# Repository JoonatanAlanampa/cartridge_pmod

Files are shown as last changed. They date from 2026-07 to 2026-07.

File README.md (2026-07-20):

# Cartridge Pmod

QSPI memory + audio Pmod for the TinyTapeout demo board and the ULX3S console
prototype. Drop-in compatible with the stock [QSPI Pmod](https://github.com/mole99/qspi-pmod)
pinout for any flash + single-PSRAM project; PMOD8 (uio[7]) carries sigma-delta
audio out instead of the second PSRAM chip select.

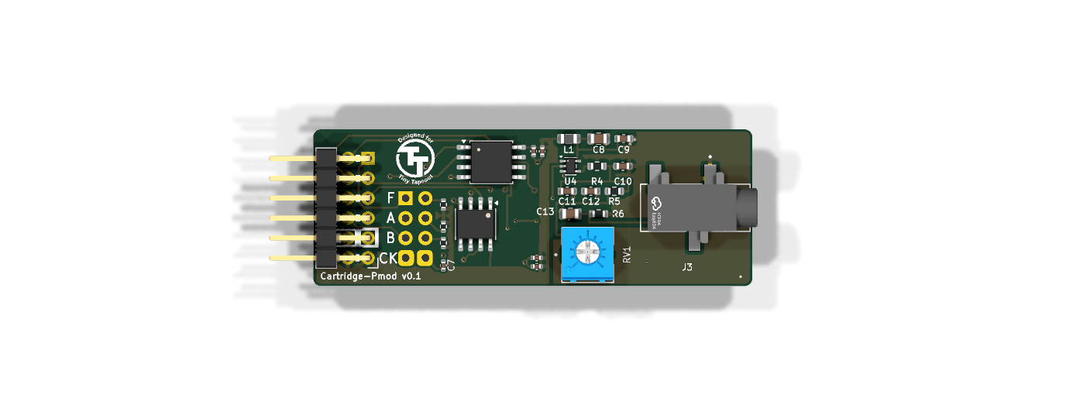
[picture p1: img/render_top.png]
Board, top


**v0.1 is at the fab**: ordered from JLCPCB 2026-07-20 (5 PCBs, 2 assembled),
tag [`fab-v0.1`](https://github.com/JoonatanAlanampa/cartridge_pmod/releases/tag/fab-v0.1). A self-checking ULX3S bring-up
bitstream is ready in [`fpga/`](fpga/README.md).

| | |
|---|---|
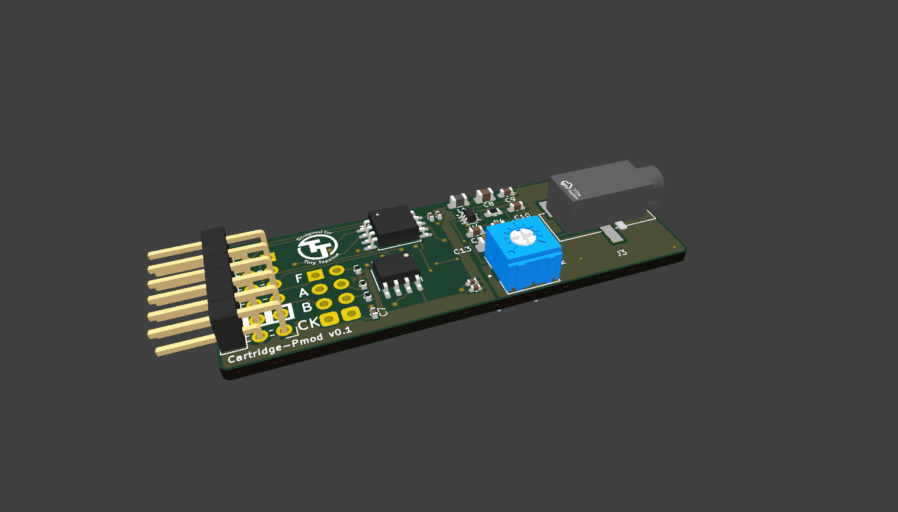
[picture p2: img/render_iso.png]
3D view
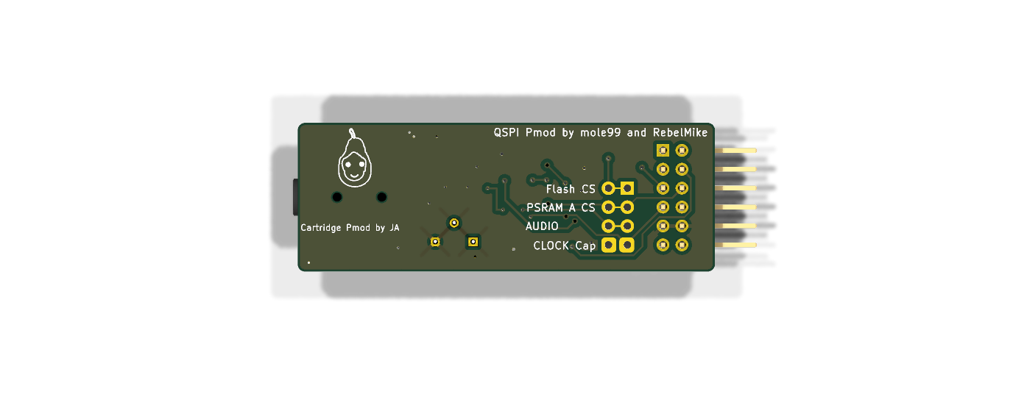
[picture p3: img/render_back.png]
Back with pearto
|  |  |
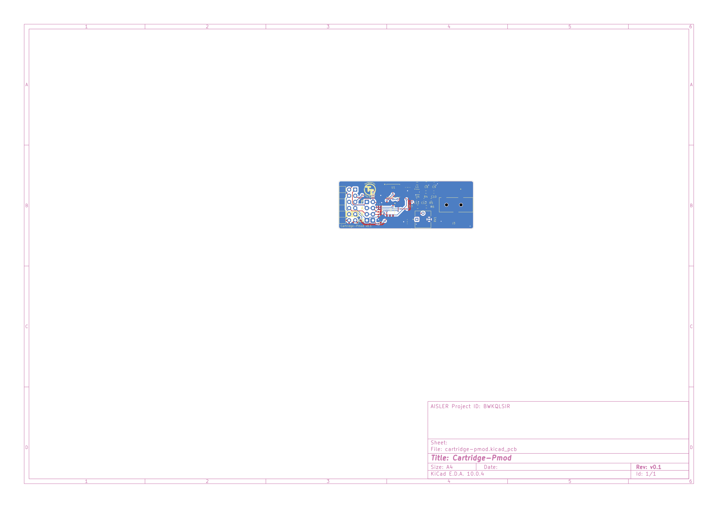
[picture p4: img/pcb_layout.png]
PCB layout
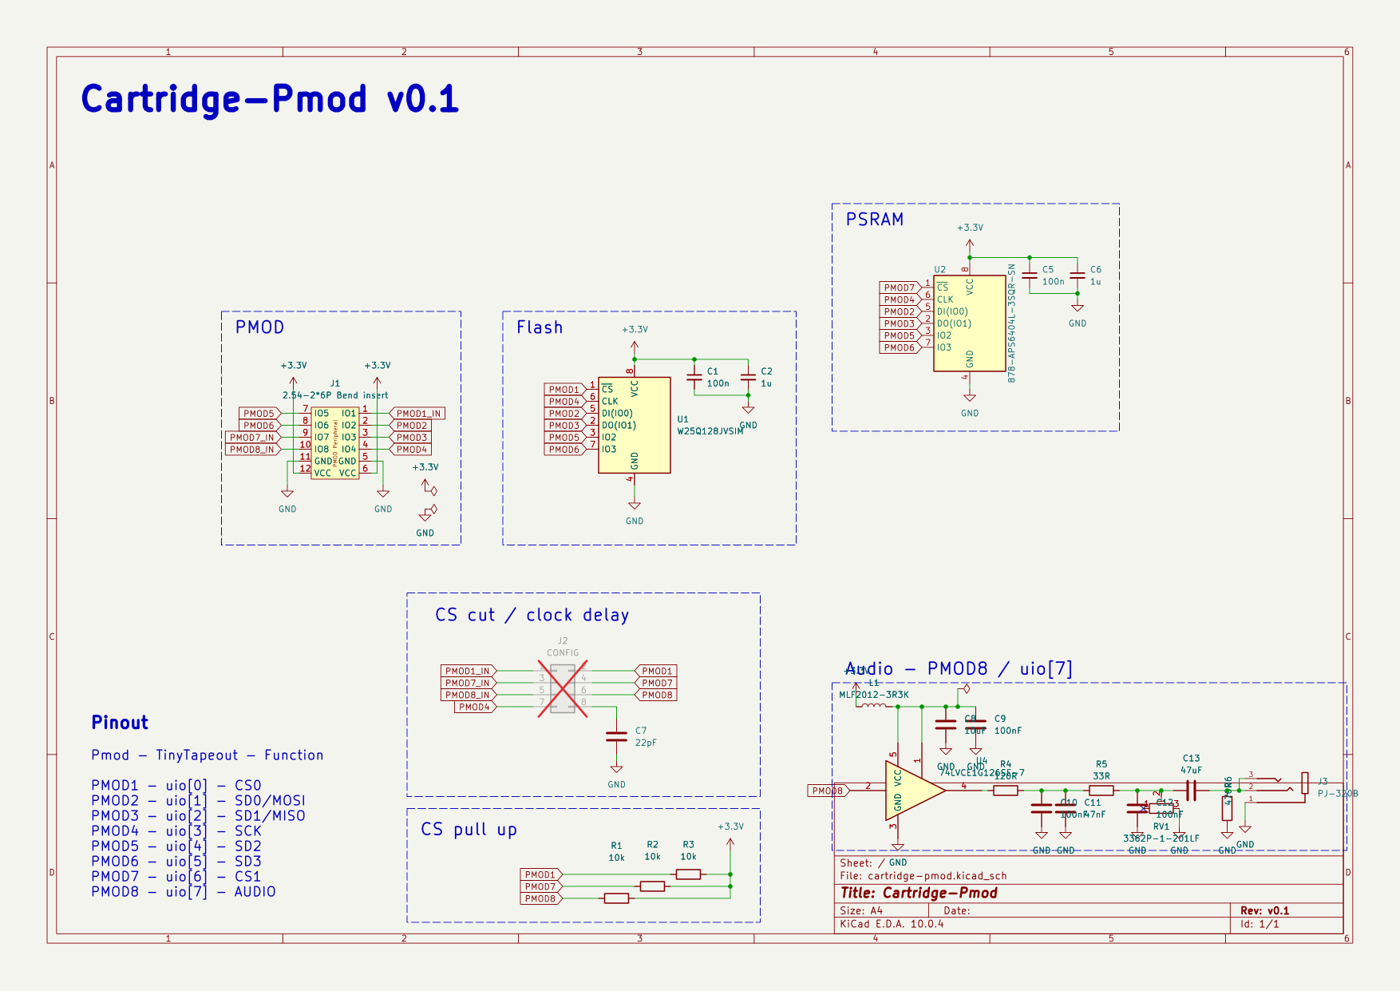
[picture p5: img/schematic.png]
Schematic
|  |  |

Full-size: [schematic PDF](cartridge-pmod.pdf) ·
[layout](img/pcb_layout.png) · [schematic PNG](img/schematic.png)

Remix of two Apache-2.0 designs:
- Memory section: [mole99/qspi-pmod](https://github.com/mole99/qspi-pmod) v2.2
  (W25Q128 16 MB flash + APS6404L 8 MB PSRAM, CONFIG jumper block, CS pull-ups)
- Audio section: [MichaelBell/tt-audio-pmod](https://github.com/MichaelBell/tt-audio-pmod)
  rev 1.0 (buffer + 2-stage RC low-pass + AC-coupled 3.5 mm jack), piezo branch dropped

## Pinout

| Pmod  | TinyTapeout | Function | Note |
|---|---|---|---|
| PMOD1 | uio[0] | CS0 (Flash)  | CONFIG jumper to isolate |
| PMOD2 | uio[1] | SD0/MOSI | |
| PMOD3 | uio[2] | SD1/MISO | |
| PMOD4 | uio[3] | SCK | CONFIG jumper pair adds 22 pF clock delay |
| PMOD5 | uio[4] | SD2 | |
| PMOD6 | uio[5] | SD3 | |
| PMOD7 | uio[6] | CS1 (PSRAM)  | CONFIG jumper to isolate |
| PMOD8 | uio[7] | AUDIO (sigma-delta / PWM in) | CONFIG jumper to isolate; ≥200 kHz carrier recommended |

## Modes

- **Console / full**: all CONFIG jumpers closed — flash + PSRAM + audio at once
  (game-console cartridge: code XIP from flash, PSRAM work RAM, audio on uio[7]).
- **Universal audio Pmod**: CS0/CS1 jumpers open — memories held in standby by
  10 k pull-ups, board is a plain audio Pmod for any project driving uio[7].
- **QSPI-compat**: audio jumper open — behaves as the stock QSPI Pmod minus
  PSRAM B (projects using only CS0/CS1 work unmodified).

## Audio chain (from tt-audio-pmod)

PMOD8 → 74LVCE1G126 buffer (ferrite-filtered 3.3 V rail, OE tied high) →
120 Ω → 100 nF‖47 nF → 33 Ω → 100 nF (2-stage RC LPF) → 200 Ω trim shunt
(volume) → 47 µF AC coupling → PJ-320B jack (tip+ring mono, 470 Ω DC
reference). Buffer input is high-impedance: audio taps the bus without
loading it.

## Status

- [x] Schematic complete, netlist machine-verified against both upstream
      designs (`tools/netlist_check.py`)
- [x] PCB layout: 56.3 × 20.1 mm, fully placed + routed (largely via pcbnew
      scripting), ERC 0 / DRC 0-unconnected, 0 silk warnings; only remaining
      DRC errors are the intentional CONFIG cut-trace feature + one upstream
      starved-thermal
- [x] Fab: **ordered at JLCPCB 2026-07-20** (tag `fab-v0.1`) — 5 PCBs,
      2 assembled (Economic, incl. the THT Pmod header), $71.76 all-in;
      see [FABRICATION.md](FABRICATION.md) for the export recipe and the
      ordering lessons (J1 rotation, PSRAM LCSC number, PCBA remark)
- [x] ULX3S bring-up harness: flash/PSRAM ID + memory test + 440 Hz test
      tone + UART report, plug orientation autodetected; simulated in both
      orientations (cocotb + icarus), 898 LUTs — see [fpga/](fpga/README.md)
- [ ] Boards arrive (~3 weeks): run the
      [first-power-up checklist](fpga/README.md#first-power-up-checklist-per-board--do-steps-1-2-before-plugging-in)

## Tools

- `tools/sch_analyze.py <file.kicad_sch>` — list all top-level elements with
  positions
- `tools/netlist_check.py [file]` — derive and print the netlist from wire
  geometry (poor man's ERC)
- `tools/build_cartridge.py` — the one-shot surgery script that generated the
  schematic from the two reference designs (kept for provenance; do not re-run)

Reference designs are vendored read-only under `refs/`.

Licensed Apache-2.0 (same as both upstream designs).

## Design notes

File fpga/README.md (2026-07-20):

# Cartridge Pmod bring-up + flash-writer on the ULX3S 85F

Self-checking harness: probes the flash + PSRAM, runs a memory test, plays a
440 Hz test tone into the audio jack, and prints a verdict on the USB serial
port. After the tests, the same bitstream turns the UART into a **flash
writer** — `flash_cartridge.py` pushes any binary image into the cartridge's
W25Q128, which is how program images get onto the cartridge for
TinyRV32-XIP boot (see `tt-riscv/fpga/`). Simulated against behavioral
W25Q128/APS6404 models: both plug orientations + a full
erase/program/verify pass (`test/`).

## Build & flash

```powershell
powershell -File fpga\synth.ps1                      # -> fpga\build\cartridge_bringup.bit
openFPGALoader -b ulx3s fpga\build\cartridge_bringup.bit
```

Simulate: `python fpga\test\run.py` (runs both plug orientations).

## First power-up checklist (per board — do steps 1-2 BEFORE plugging in!)

1. **Bare-board short check** (multimeter, cartridge alone on the bench):
   continuity between the Pmod plug's VCC (pins 6/12, the column nearest the
   board) and GND (pins 5/11) must be OPEN (a capacitor charge blip is fine,
   a hard beep is not).
2. **Plug position**: cartridge goes into the **J1 header, pins 1-12** — the
   6 columns at the END of the left female header. ULX3S silk numbers the
   pins; the cartridge's VCC/GND columns must land on pins 1/2 (3.3V) and
   3/4 (GND). Verify once with the meter: cartridge VCC pin to ULX3S 3.3V
   should beep. Which cartridge ROW lands on GP vs GN does not matter — the
   bitstream autodetects it (LED4 tells you which).
3. Flash the bitstream, open a serial terminal at **115200 8N1** on the
   ULX3S FTDI port. Report format:

   ```
   CARTRIDGE-PMOD BRINGUP
   MAP A                    <- or B; ! = flash never answered (both rows tried)
   FLASH EF4018 PASS        <- W25Q128 JEDEC ID
   PSRAM 0D5D PASS          <- APS6404 MF+KGD
   MEM PASS                 <- 2 write/read patterns + aliasing re-read
   FLASH@0 FFFFFFFF         <- first 4 flash bytes (blank chip = FF)
   DONE
   ```

4. **LEDs**: 0 heartbeat, 1 flash OK, 2 PSRAM OK, 3 mem OK, 4 mapping B,
   5 done, 6 any-fail, 7 audio on. **BTN1 re-runs** the whole sequence.
5. **Audio**: after all tests pass, a 440 Hz sine plays on the cartridge
   jack (sigma-delta through the RC + buffer chain). Headphones in, set
   level with RV1 (small screwdriver). Verifies the whole analog path.
6. If `MAP !` / all-fail: check the CONFIG jumpers on the cartridge back
   (F and A rows must be in their default state), re-seat the Pmod, check
   3.3V on the cartridge VCC pin while powered.

## Flashing a program image

After the bring-up report (any time the LEDs show DONE), the UART accepts
binary flash-writer commands. From the PC:

```powershell
pip install pyserial          # once
python fpga\flash_cartridge.py COM7 hello.bin          # erase+write+verify
python fpga\flash_cartridge.py COM7 img.bin --base 0x10000
```

(Find the COM port in Device Manager — the ULX3S FTDI channel; on Linux
`/dev/ttyUSB0`.) The script waits out the report, handshakes on the JEDEC
ID, erases the covered 4 KB sectors, programs 256-byte pages, and reads
everything back. Protocol (MSB-first fields, handled in `bringup_top.sv`
with WREN + SR1 busy-polling internal):

| cmd | bytes | reply |
|-----|---|---|
| `I` | — | 3 ID bytes (`EF 40 18`) |
| `E` | addr24 | `K` after sector erase completes |
| `P` | addr24 + 256 data | `K` after page program completes |
| `R` | addr24 | 256 bytes read from addr |

Then flash `tt-riscv`'s `rv32_cartridge.bit` — TinyRV32 boots the image
in place. Day-one sequence: bring-up PASS -> flash hello.bin -> swap
bitstream -> "Hello" on the same serial port.

## What this proves / what's next

PASS here = the cartridge hardware is fully validated for the console
project: QSPI bus wiring, both memories, the audio chain, and the TT-pinout
compatibility (pins 1-7 identical to the stock QSPI Pmod).

Next steps on this same setup:
- quad-mode + clock sweep (the bring-up runs 12.5 MHz single-bit SPI)
- race-the-beam console prototype (video via ULX3S GPDI while waiting for
  the Tiny VGA Pmod)

## Notes

- The APS6404 tCEM (8 us max CS-low) is respected by keeping bursts to
  4 bytes; the testbench model enforces it with a fatal assertion.
- SD2/SD3 (flash /WP, /HOLD) are actively driven high during SPI — they
  have no pull-ups on the cartridge.
- The ULX3S J1 power pins feed from the "2V5_3V3" net — stock boards ship
  it at 3.3 V; if yours was modified for 2.5 V I/O, put it back before
  plugging the cartridge.

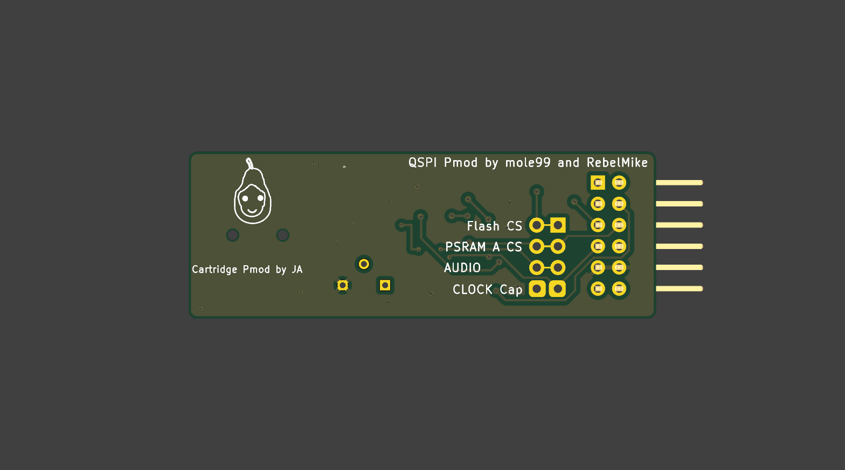
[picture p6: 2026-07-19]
render_bottom.png

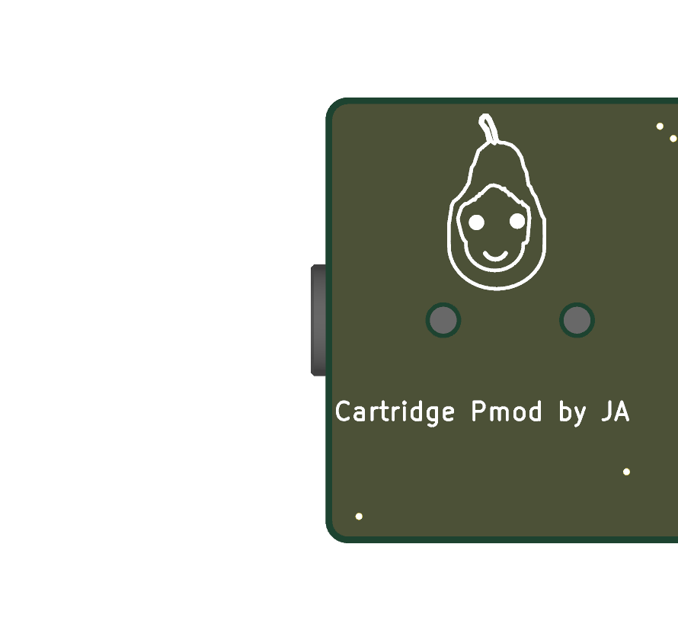
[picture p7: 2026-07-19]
rb_crop.png

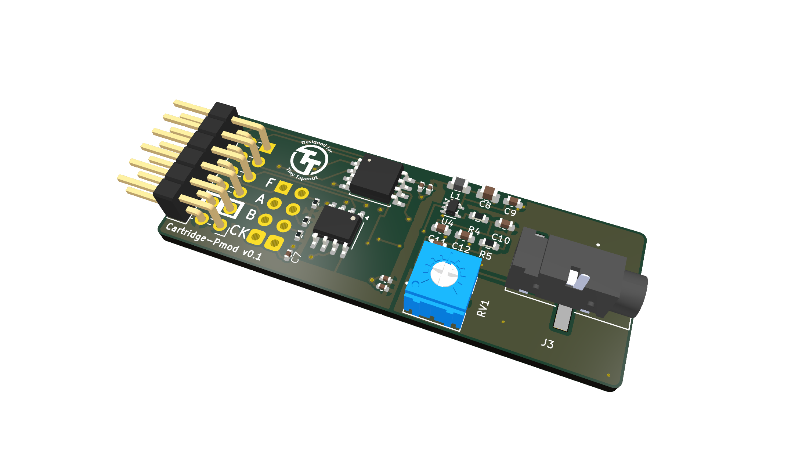
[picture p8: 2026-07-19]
render_3d.png

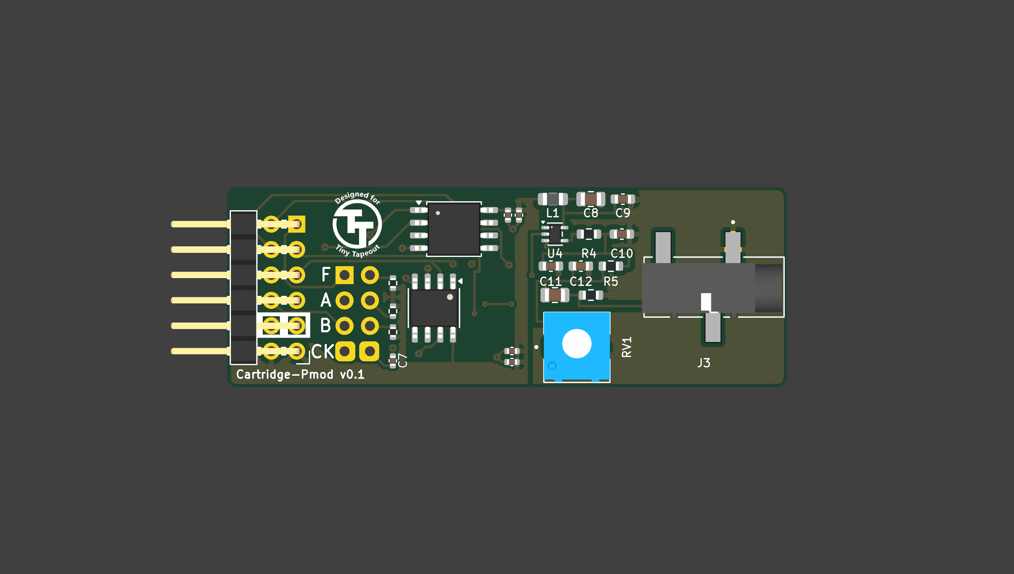
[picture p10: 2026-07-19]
render_zoom.png

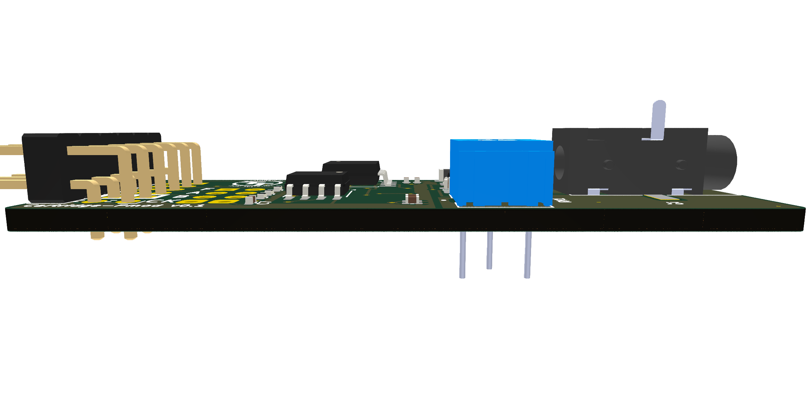
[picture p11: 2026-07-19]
render_side.png

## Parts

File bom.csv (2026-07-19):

Reference | Value | Footprint | QUANTITY | LCSC Part | MPN
C1,C5 | 100n | Capacitor_SMD:C_0402_1005Metric | 2 |  | 0402YC104KAT2A
C2,C6 | 1u | Capacitor_SMD:C_0402_1005Metric | 2 |  | C0402C105M9PAC
C7 | 22pF | Capacitor_SMD:C_0402_1005Metric | 1 |  | 0402CG220J500NT
C8 | 10uF | Capacitor_SMD:C_0805_2012Metric | 1 | C15850
C9,C10,C12 | 100nF | Capacitor_SMD:C_0603_1608Metric | 3 | C14663
C11 | 47nF | Capacitor_SMD:C_0603_1608Metric | 1 | C1622
C13 | 47uF | Capacitor_SMD:C_0805_2012Metric | 1 | C16780
J1 | 2.54-2*6P Bend insert | tt:PinHeader_2x06_P2.54mm_PMODPeriph2B | 1 | C60565 | 2.54-2*6P
J2 | CONFIG | Connector_PinHeader_2.54mm:PinHeader_2x04_P2.54mm_Vertical | 1
J3 | PJ-320B | LCSC:BOOMELE_PJ-320B | 1 | C2884998
L1 | MLF2012-3R3K | Inductor_SMD:L_0805_2012Metric | 1 | C2941578
R1-R3 | 10k | Resistor_SMD:R_0402_1005Metric | 3 |  | 0402WGF1002TCE
R4 | 120R | Resistor_SMD:R_0603_1608Metric | 1 | C22787
R5 | 33R | Resistor_SMD:R_0603_1608Metric | 1 | C23140
R6 | 470R | Resistor_SMD:R_0603_1608Metric | 1 | C23179
RV1 | 3362P-1-201LF | LCSC:TRIM_3362P-1-102 | 1 | C124581
U1 | W25Q128JVSIM | Package_SO:SOIC-8_5.23x5.23mm_P1.27mm | 1 |  | W25Q128JVSIM
U2 | 878-APS6404L-3SQR-SN | Package_SO:SOP-8_3.9x4.9mm_P1.27mm | 1 |  | APS6404L-3SQR-SN
U4 | 74LVCE1G126SE-7 | Package_TO_SOT_SMD:SOT-353_SC-70-5 | 1 | C842506

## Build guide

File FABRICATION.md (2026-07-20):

# Fabrication export guide (JLCPCB, PCB + SMT assembly)

## ORDERED 2026-07-20 (v0.1, commit 8dd7671, tag fab-v0.1)

5 PCBs + 2 assembled (Economic, top side), $71.76 all-in via Global Standard
Direct Line (13-16 business days). Breakdown: $52.34 merchandise, $16.26
shipping (incl $6.93 prepaid customs-duty deposit), $18.42->$13.16 VAT via
IOSS, -$10 coupon. NOTE: since 2026-07-01 the EU charges customs duty below
EUR 150 too — Direct Line prepays it; courier (non-DDP) options risk a
disbursement fee at the door; DHL DDP was quoted +$24.50 over Direct Line.

Lessons from the actual order (v0.1):
- J1 rendered 90 deg rotated in the JLC placement preview (custom TT
  footprint, not in their rotation DB) — fixed with the preview's rotate
  button: pins must extend off the LEFT board edge. Re-check every order.
- Pin-1 ground truth for the preview check (board title bottom-left):
  U1 dot TOP-LEFT, U2 dot TOP-RIGHT, U4 3-pin side LEFT + dot TOP-LEFT.
- U2 PSRAM has no LCSC number in our BOM (upstream sourced via Mouser):
  match manually to APS6404L-3SQR-SN = LCSC C5333729 (~$2.94).
- C1/C5, C2/C6, R1-R3 raise "comment mismatch" warnings (our BOM carries
  MPNs, not LCSC codes) — matched parts C1525 / C52923 / C25744 verified
  correct, just tick to confirm.
- PCBA remark used (J2 is NOT in the uploaded BOM/CPL, describe visually):
  "J1 (the only THT part in the BOM, right-angle pin header): body sits on
  the board, pins intentionally extend past the LEFT board edge, orientation
  as set in the placement preview. J3 (audio jack): barrel intentionally
  overhangs the RIGHT board edge. The unpopulated 2x4 through-hole pad grid
  next to the 'F A B CK' silk labels is a solder-jumper feature -
  intentionally empty, do not populate. No other special requirements."

Target: 5 boards, assembled front side. Everything below
was verified against this project with KiCad 10.0.4 on Windows.

## Pre-flight (already done for v0.1, re-check after any edit)

1. ERC on the schematic: 0 errors
   (`kicad-cli sch erc --severity-error cartridge-pmod.kicad_sch`).
2. DRC on the board: 0 unconnected; only the 23 known-ignorable errors
   (22 CONFIG-jumper cut-trace + 1 upstream starved-thermal on R1)
   (`kicad-cli pcb drc cartridge-pmod.kicad_pcb`).
3. Zones refilled (open PCB in GUI, press **B**, save — or any tools/ script
   that ends with `ZONE_FILLER`).
4. Supplier fields present **on the board**, not only the schematic: the
   Fabrication Toolkit reads footprint fields, so `LCSC Part` must be pushed
   across with Tools → Update PCB from Schematic (F8, "update fields" ticked).
   Without it the audio-section LCSC numbers export blank. Fixed 2026-07-20.
5. J1 (Pmod header) is **JLC-assembled** (DNP cleared 2026-07-20, LCSC
   C60565, THT economic assembly). J2 (CONFIG solder jumpers) stays DNP —
   export with the exclude-DNP option so it drops out of BOM + placement.
6. Silkscreen is DRC-clean (0 silk warnings since 2026-07-20: J1's off-edge
   pin drawings deleted, all audio-section labels placed, C13/R6 shown).
7. Board committed + pushed.

## Option A — Fabrication Toolkit plugin (recommended, one click)

1. Open KiCad → **Plugin and Content Manager** → install **Fabrication
   Toolkit** (by bennymeg; made specifically for JLCPCB).
2. Open the PCB editor, click the Fabrication Toolkit icon in the toolbar.
3. It writes a `production/` folder containing:
   - `gerbers.zip` (all copper/mask/silk/edge layers + drill files)
   - `bom.csv` (grouped by value+footprint, with the **LCSC Part** field)
   - `positions.csv` (component placement / CPL, JLC-rotation-corrected)
4. Upload to jlcpcb.com — see "Ordering" below.

Headless equivalent (no GUI; same output, verified 2026-07-20):

```powershell
& "$env:LOCALAPPDATA\Programs\KiCad\10.0\bin\python.exe" -c @'
import sys, runpy
sys.path.insert(0, r"C:\Users\Joonatan Alanampa\Documents\KiCad\10.0\3rdparty\plugins")
sys.argv = ["cli", "-p", r"cartridge-pmod.kicad_pcb", "-t", "-f", "-e", "-nI"]
runpy.run_module("com_github_bennymeg_JLC-Plugin-for-KiCad.cli", run_name="__main__")
'@
```

(`-t` rotation fixes, `-f` zone refill, `-e` exclude DNP → keeps J2 out,
`-nI` non-interactive. `runpy` because the plugin dir name has hyphens.)

## Option B — pure kicad-cli (no GUI, scriptable)

Run from the project directory
(`$cli = "$env:LOCALAPPDATA\Programs\KiCad\10.0\bin\kicad-cli.exe"`):

```powershell
# gerbers (copper, mask, silk both sides, board edge)
& $cli pcb export gerbers --output fab/ `
    --layers F.Cu,B.Cu,F.Mask,B.Mask,F.Silkscreen,B.Silkscreen,Edge.Cuts `
    cartridge-pmod.kicad_pcb
# drill files (Excellon, PTH+NPTH merged is fine for JLC)
& $cli pcb export drill --output fab/ --format excellon `
    --excellon-units mm cartridge-pmod.kicad_pcb
# placement file, front side, CSV in mm
& $cli pcb export pos --output fab/positions.csv --format csv --units mm `
    --side front cartridge-pmod.kicad_pcb
# BOM with LCSC numbers
& $cli sch export bom --output fab/bom.csv `
    --fields "Reference,Value,Footprint,${'$'}{QUANTITY},LCSC Part,MPN" `
    cartridge-pmod.kicad_sch
# zip the gerbers + drill for upload
Compress-Archive fab/*.gbr, fab/*.drl fab/gerbers.zip
```

Caveat vs Option A: JLC wants specific CPL column names
(Designator, Mid X, Mid Y, Layer, Rotation) and some footprints need
rotation offsets — the Fabrication Toolkit handles both automatically,
kicad-cli output may need manual column renaming and rotation fixes in the
JLC preview. Prefer Option A for ordering; use Option B for CI/checks.

## Ordering at jlcpcb.com

1. **Add gerber file** → upload `gerbers.zip`. Check the rendered preview
   (board outline 56.3 x 20.1 mm, both silk sides, pearto visible on back).
2. PCB options: 2 layers, 1.6 mm, HASL(lead-free ok), any color, qty 5.
   Leave everything else default. "Remove Order Number" → "Specify a
   location" is NOT set up on this board — accept the printed order number
   or pay the small fee to remove it.
3. Enable **PCB Assembly**: Economic, top side, qty 2 or 5.
4. Upload `bom.csv` and `positions.csv`.
5. Parts matching page — check each line:
   - Audio section parts all carry explicit LCSC numbers
     (U4 C842506, L1 C2941578, C8 C15850, C9/C10/C12 C14663, C11 C1622,
     R4 C22787, R5 C23140, R6 C23179, RV1 C124581, J3 C2884998, J1 C60565).
   - Memory section (U1 W25Q128JVSIM, U2 APS6404L-3SQR-SN, 0402 R/C) has
     MPNs but no LCSC field — JLC usually auto-matches by MPN; verify the
     match, or search the LCSC number manually and paste it in.
   - **Do-not-place**: J2 CONFIG header is a solder-jumper pattern +
     optional pin header — confirm whether a physical header is wanted;
     if not, mark J2 DNP (the jumper pads still work with solder blobs).
6. Placement preview: verify U1/U2/U4 pin-1 orientation and RV1/J3 outline
   vs pads (these are the rotation-risk parts). Fix rotations in the JLC
   editor if a part renders rotated.
7. THT parts: J1 (Pmod header, C60565) is in the BOM/CPL for JLC economic
   THT assembly — verify in the parts-matching page that JLC accepts it for
   economic assembly; if it's flagged unsupported, either switch the order
   to Standard assembly or mark J1 "Do not place" in the JLC editor and
   hand-solder it (Pinecil fallback). J3's TH legs are anchors only, SMT
   soldered.
8. Order. Economic assembly typically adds ~1 week.

## After ordering

- Tag the repo: `git tag fab-v0.1 && git push --tags`.
- First power-up checklist: continuity 3V3-GND (multimeter, before first
  plug-in!), then flash/PSRAM ID read via TT demo board or ULX3S harness,
  then audio: drive uio7 with a sigma-delta/PWM tone >= 200 kHz carrier.

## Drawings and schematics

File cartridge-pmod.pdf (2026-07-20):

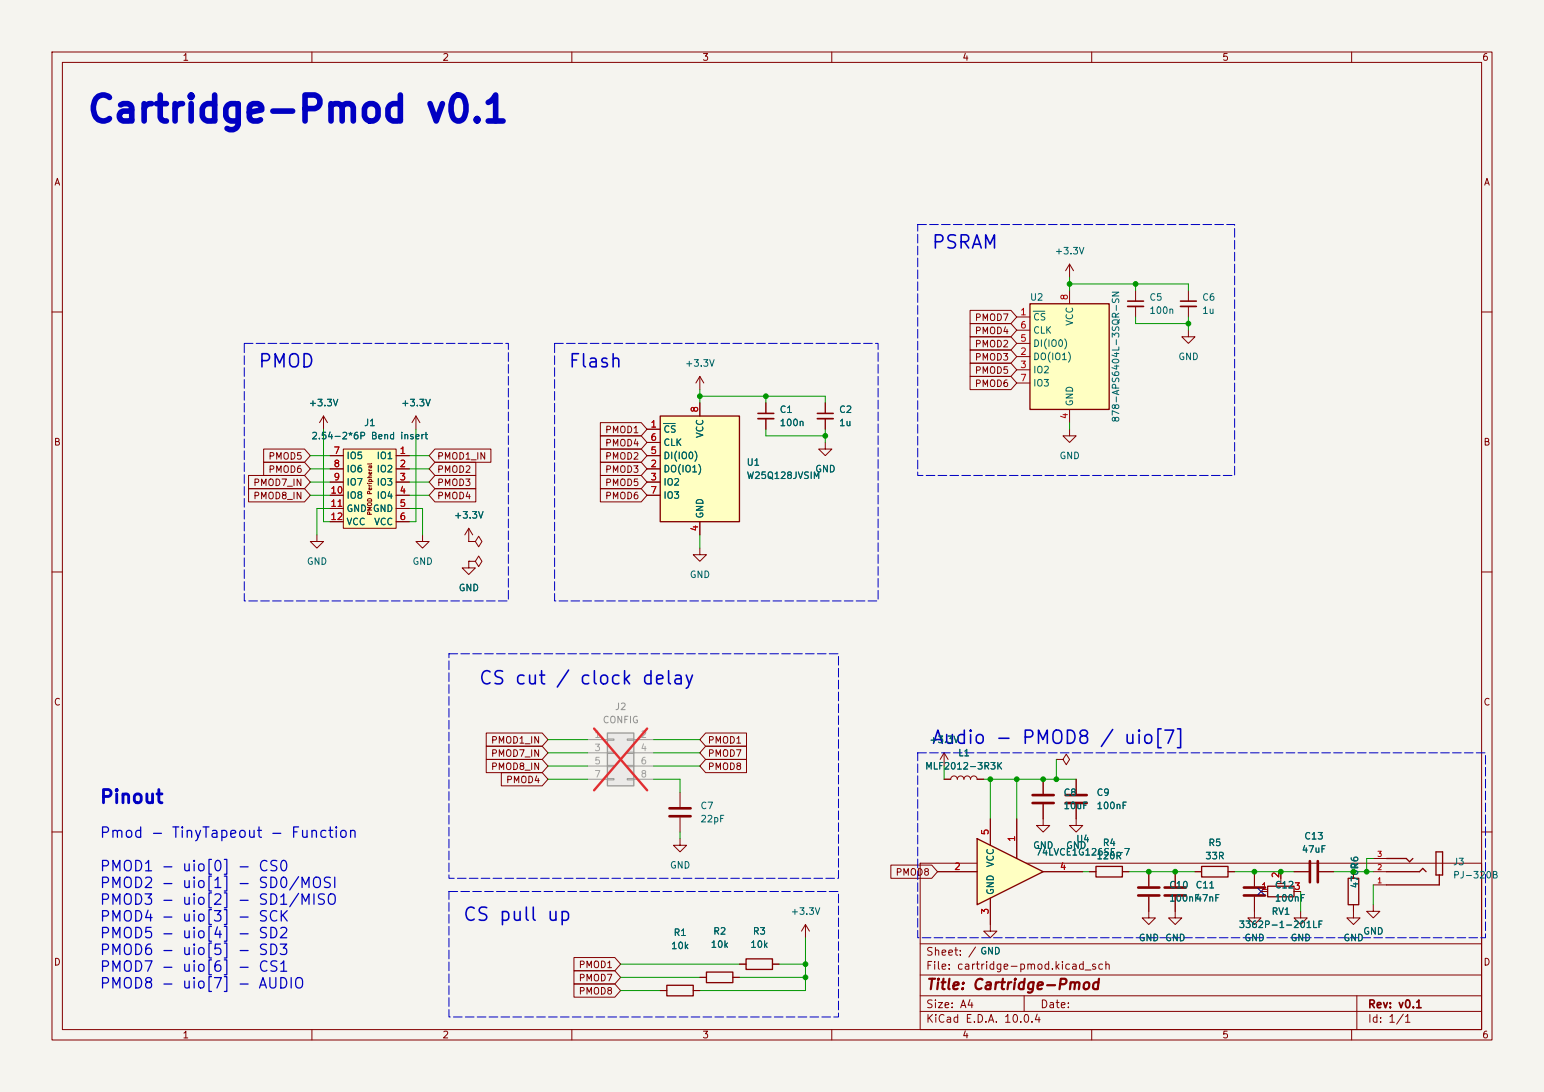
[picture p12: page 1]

CS cut / clock delay

Size: A4 | Rev: v0.1
KiCad E.D.A. 10.0.4 | Id: 1/1

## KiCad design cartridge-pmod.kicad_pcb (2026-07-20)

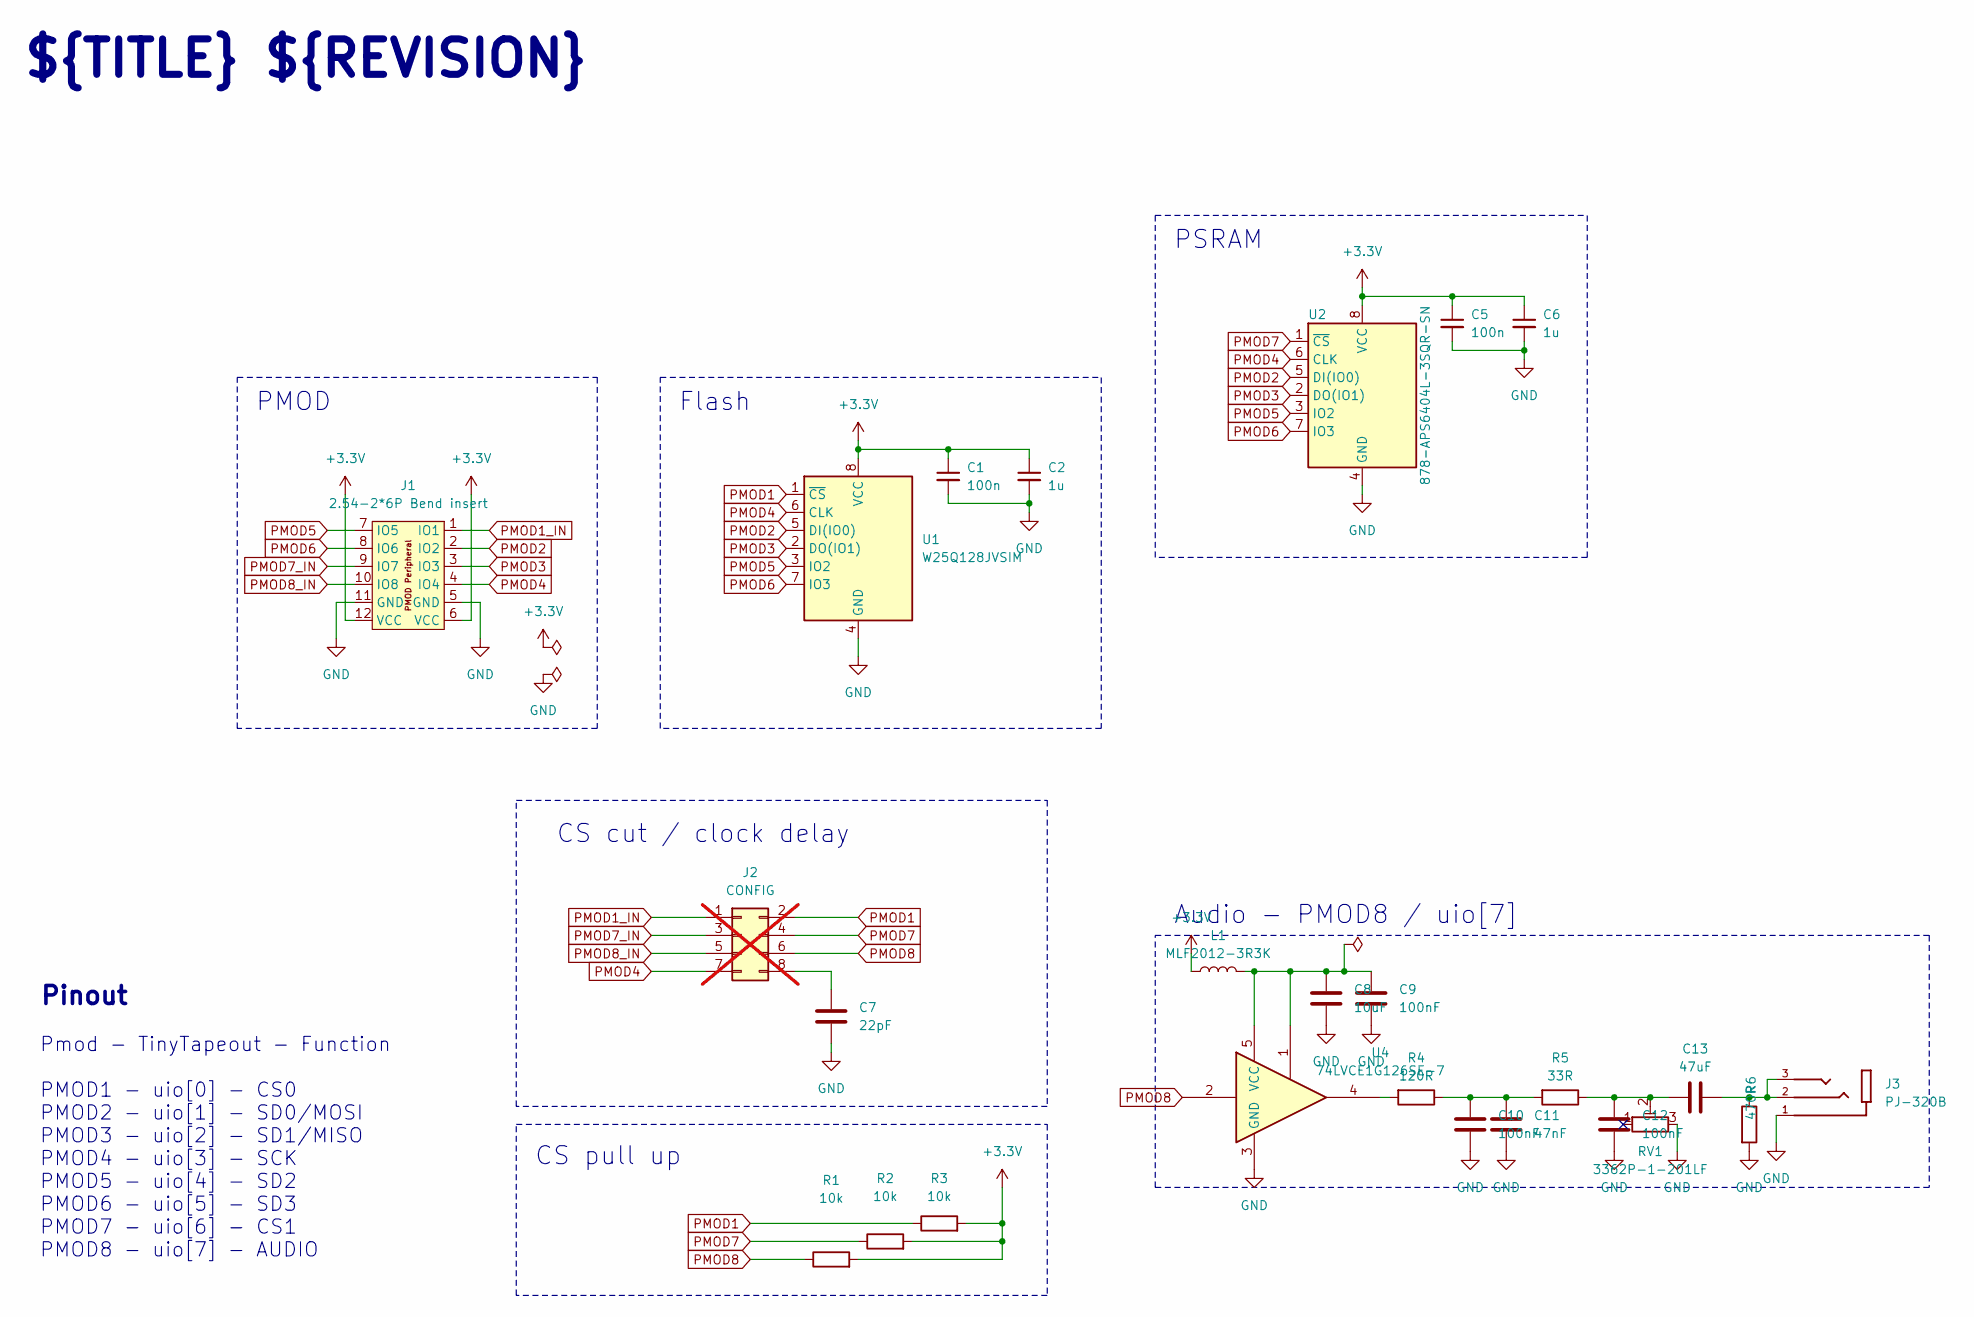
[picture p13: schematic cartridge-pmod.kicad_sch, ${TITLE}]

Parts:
C1, C5: 100n; C_0402_1005Metric; MPN 0402YC104KAT2A
C2, C6: 1u; C_0402_1005Metric; MPN C0402C105M9PAC
C7: 22pF; C_0402_1005Metric; MPN 0402CG220J500NT
C8: 10uF; C_0805_2012Metric; LCSC Part C15850
C9, C10, C12: 100nF; C_0603_1608Metric; LCSC Part C14663
C11: 47nF; C_0603_1608Metric; LCSC Part C1622
C13: 47uF; C_0805_2012Metric; LCSC Part C16780
J1: 2.54-2*6P Bend insert; PinHeader_2x06_P2.54mm_PMODPeriph2B; MPN 2.54-2*6P; LCSC Part C60565
J2: CONFIG; PinHeader_2x04_P2.54mm_Vertical; not fitted
J3: PJ-320B; BOOMELE_PJ-320B; LCSC Part C2884998
L1: MLF2012-3R3K; L_0805_2012Metric; LCSC Part C2941578
R1, R2, R3: 10k; R_0402_1005Metric; MPN 0402WGF1002TCE
R4: 120R; R_0603_1608Metric; LCSC Part C22787
R5: 33R; R_0603_1608Metric; LCSC Part C23140
R6: 470R; R_0603_1608Metric; LCSC Part C23179
RV1: 3362P-1-201LF; TRIM_3362P-1-102; LCSC Part C124581
U1: W25Q128JVSIM; SOIC-8_5.23x5.23mm_P1.27mm; MPN W25Q128JVSIM
U2: 878-APS6404L-3SQR-SN; SOP-8_3.9x4.9mm_P1.27mm; MPN APS6404L-3SQR-SN
U4: 74LVCE1G126SE-7; SOT-353_SC-70-5; LCSC Part C842506

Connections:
+3.3V: C1.1, C2.1, C5.1, C6.1, J1.6 (VCC), J1.12 (VCC), L1.1, R1.2, R2.2, R3.2, U1.8 (VCC), U2.8 (VCC)
AUDIO_BUF: R4.2, U4.4
AUDIO_N1: C10.1, C11.1, R4.1, R5.2
AUDIO_N2: C12.1, C13.2, R5.1, RV1.2
AUDIO_OUT: C13.1, J3.2, J3.3, R6.1
AUDIO_VCCA: C8.1, C9.1, L1.2, U4.1, U4.5 (VCC)
GND: C1.2, C2.2, C5.2, C6.2, C7.1, C8.2, C9.2, C10.2, C11.2, C12.2, J1.5 (GND), J1.11 (GND), J3.1, R6.2, RV1.3, U1.4 (GND), U2.4 (GND), U4.3 (GND)
unnamed: C7.2, J2.8
PMOD1: J2.2, R3.1, U1.1 (~CS)
PMOD1_IN: J1.1 (IO1), J2.1
PMOD2: J1.2 (IO2), U1.5 (DI(IO0)), U2.5 (DI(IO0))
PMOD3: J1.3 (IO3), U1.2 (DO(IO1)), U2.2 (DO(IO1))
PMOD4: J1.4 (IO4), J2.7, U1.6 (CLK), U2.6 (CLK)
PMOD5: J1.7 (IO5), U1.3 (IO2), U2.3 (IO2)
PMOD6: J1.8 (IO6), U1.7 (IO3), U2.7 (IO3)
PMOD7: J2.4, R2.1, U2.1 (~CS)
PMOD7_IN: J1.9 (IO7), J2.3
PMOD8: J2.6, R1.1, U4.2
PMOD8_IN: J1.10 (IO8), J2.5

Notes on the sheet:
CS cut / clock delay
PMOD
Flash
CS pull up
${TITLE} ${REVISION}
PSRAM
Pmod - TinyTapeout - Function PMOD1 - uio[0] - CS0 PMOD2 - uio[1] - SD0/MOSI PMOD3 - uio[2] - SD1/MISO PMOD4 - uio[3] - SCK PMOD5 - uio[4] - SD2 PMOD6 - uio[5] - SD3 PMOD7 - uio[6] - CS1 PMOD8 - uio[7] - AUDIO
Pinout
Audio - PMOD8 / uio[7]

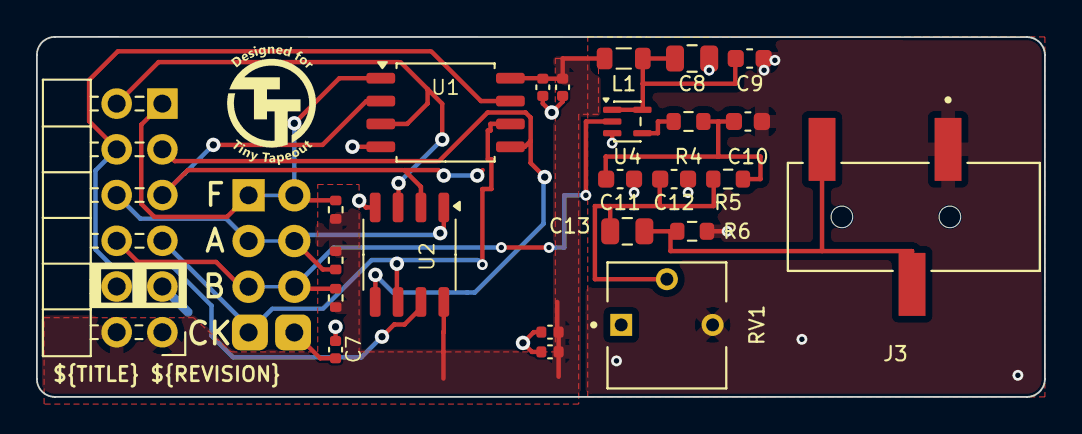
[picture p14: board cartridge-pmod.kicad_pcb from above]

Board: 2 copper layers, 56.0 x 20.0 mm, 25 parts (0 on the bottom side), 19 nets.

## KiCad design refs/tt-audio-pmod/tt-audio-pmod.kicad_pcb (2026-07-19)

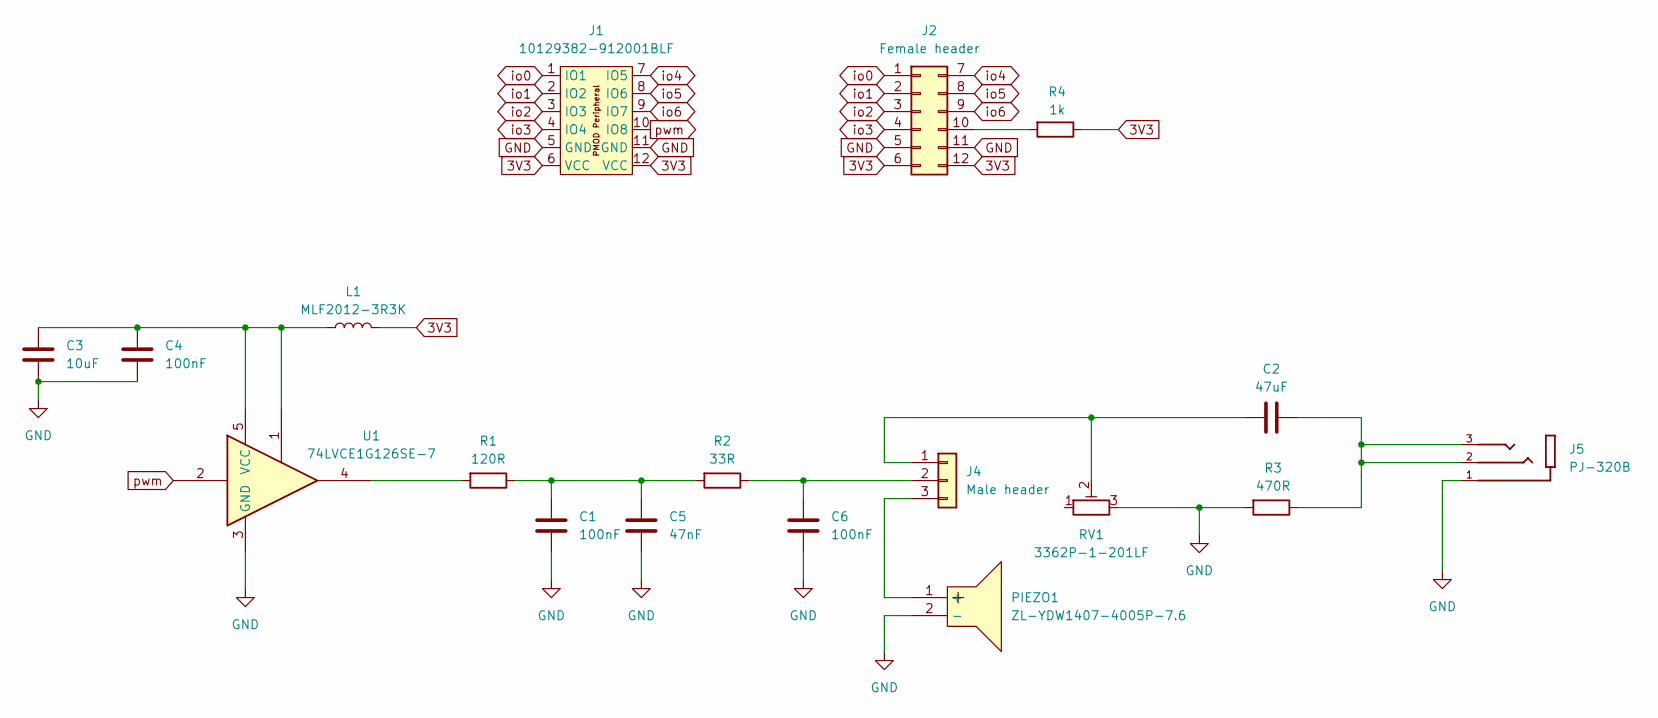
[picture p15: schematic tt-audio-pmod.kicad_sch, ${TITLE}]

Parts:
C1, C4, C6: 100nF; C_0603_1608Metric; LCSC Part C14663
C2: 47uF; C_0805_2012Metric; LCSC Part C16780
C3: 10uF; C_0805_2012Metric; LCSC Part C15850
C5: 47nF; C_0603_1608Metric; LCSC Part C1622
J1: 10129382-912001BLF; PinHeader_2x06_P2.54mm_PMODPeriph2B; LCSC Part C60565
J2: Female header; PinSocket_2x06_P2.54mm_Vertical_Column; LCSC Part C92269
J4: Male header; PinHeader_1x03_P2.54mm_Vertical; LCSC Part C49257
J5: PJ-320B; BOOMELE_PJ-320B; LCSC Part C2884998
L1: MLF2012-3R3K; L_0805_2012Metric; LCSC Part C2941578
PIEZO1: ZL-YDW1407-4005P-7.6; BUZ-TH_BD14.0-P7.60-D0.7-FD; LCSC Part C219740
R1: 120R; R_0603_1608Metric; LCSC Part C22787
R2: 33R; R_0603_1608Metric; LCSC Part C23140
R3: 470R; R_0603_1608Metric; LCSC Part C23179
R4: 1k; R_0603_1608Metric; LCSC Part C21190
RV1: 3362P-1-201LF; TRIM_3362P-1-102; LCSC Part C124581
U1: 74LVCE1G126SE-7; SOT-353_SC-70-5; LCSC Part C842506

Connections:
3V3: J1.6 (VCC), J1.12 (VCC), J2.6, J2.12, L1.2, R4.1
GND: C1.2, C3.2, C4.2, C5.2, C6.2, J1.5 (GND), J1.11 (GND), J2.5, J2.11, J5.1, PIEZO1.2 (-), R3.2, RV1.3, U1.3 (GND)
unnamed: C1.1, C5.1, R1.1, R2.2
unnamed: C2.1, J5.2, J5.3, R3.1
unnamed: J2.10, R4.2
unnamed: C2.2, J4.1, RV1.2
unnamed: C6.1, J4.2, R2.1
unnamed: J4.3, PIEZO1.1 (+)
unnamed: R1.2, U1.4
unnamed: C3.1, C4.1, L1.1, U1.1, U1.5 (VCC)
io0: J1.1 (IO1), J2.1
io1: J1.2 (IO2), J2.2
io2: J1.3 (IO3), J2.3
io3: J1.4 (IO4), J2.4
io4: J1.7 (IO5), J2.7
io5: J1.8 (IO6), J2.8
io6: J1.9 (IO7), J2.9
pwm: J1.10 (IO8), U1.2

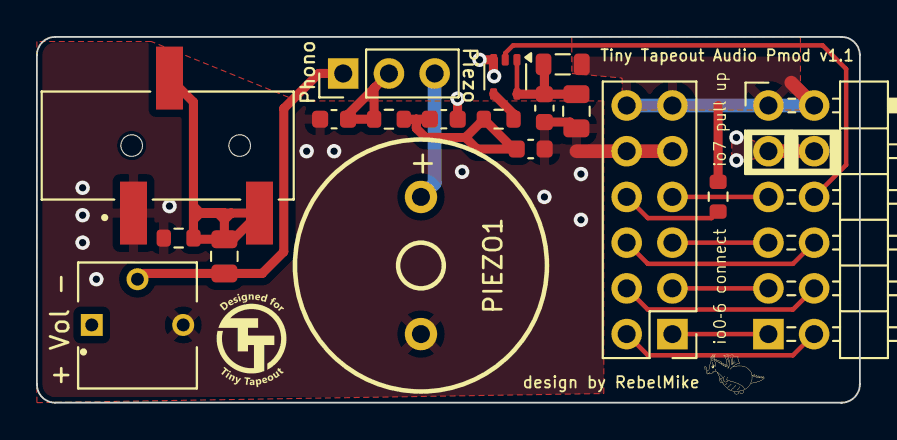
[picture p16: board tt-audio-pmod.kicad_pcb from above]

Board: 2 copper layers, 45.7 x 20.3 mm, 18 parts (0 on the bottom side), 18 nets.

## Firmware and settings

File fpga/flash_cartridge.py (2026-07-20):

#!/usr/bin/env python3
"""flash_cartridge.py — write a binary image into the Cartridge Pmod's
W25Q128 through the bring-up bitstream's UART flash-writer.

    python flash_cartridge.py COM7 hello.bin [--base 0x000000] [--no-verify]

Needs pyserial (pip install pyserial). Flash the bring-up bitstream first
(openFPGALoader -b ulx3s fpga/build/cartridge_bringup.bit), let the power-up
report finish (or just run this — it waits for the line to go quiet).

Protocol (all fields MSB first, gateware side in bringup_top.sv):
    'I'                  -> 3 bytes JEDEC ID (EF 40 18)
    'E' + addr24         -> 4 KB sector erase, 'K' when done
    'P' + addr24 + 256B  -> page program, 'K' when done
    'R' + addr24         -> 256 bytes read back
"""
import argparse
import sys
import time

try:
    import serial
except ImportError:
    sys.exit("pyserial missing: pip install pyserial")

SECTOR = 4096
PAGE = 256


def drain(port, quiet_s=0.5):
    """Swallow the bring-up report: wait until the line is quiet."""
    port.timeout = quiet_s
    while True:
        if not port.read(4096):
            return


def expect_k(port, what, timeout_s=3.0):
    port.timeout = timeout_s
    r = port.read(1)
    if r != b"K":
        sys.exit(f"{what}: expected 'K', got {r!r}")


def main():
    ap = argparse.ArgumentParser()
    ap.add_argument("port", help="serial port (COM7, /dev/ttyUSB0, ...)")
    ap.add_argument("binfile")
    ap.add_argument("--base", type=lambda x: int(x, 0), default=0,
                    help="flash byte address to write at (default 0)")
    ap.add_argument("--no-verify", action="store_true")
    args = ap.parse_args()

    if args.base % SECTOR:
        sys.exit(f"--base must be {SECTOR}-aligned")

    data = open(args.binfile, "rb").read()
    if not data:
        sys.exit("empty image")
    print(f"{args.binfile}: {len(data)} bytes -> flash @0x{args.base:06X}")

    port = serial.Serial(args.port, 115200, dsrdtr=False, rtscts=False)
    port.dtr = False
    port.rts = False
    print("waiting for the bring-up report to finish...")
    drain(port)

    # handshake
    for attempt in range(3):
        port.reset_input_buffer()
        port.write(b"I")
        port.timeout = 1.0
        fid = port.read(3)
        if fid == b"\xEF\x40\x18":
            break
        print(f"  ID attempt {attempt + 1}: got {fid.hex() or 'nothing'}")
    else:
        sys.exit("no valid flash ID — is the bring-up bitstream loaded "
                 "and the cartridge plugged in / passing its tests?")
    print("flash ID OK (EF 40 18)")

    end = args.base + len(data)
    sectors = range(args.base, end, SECTOR)
    for i, s in enumerate(sectors):
        port.write(b"E" + s.to_bytes(3, "big"))
        expect_k(port, f"erase @0x{s:06X}", timeout_s=5.0)
        print(f"\rerase  {i + 1}/{len(sectors)} sectors", end="")
    print()

    npages = (len(data) + PAGE - 1) // PAGE
    for i in range(npages):
        chunk = data[i * PAGE:(i + 1) * PAGE].ljust(PAGE, b"\xFF")
        addr = args.base + i * PAGE
        port.write(b"P" + addr.to_bytes(3, "big") + chunk)
        expect_k(port, f"program @0x{addr:06X}")
        print(f"\rwrite  {i + 1}/{npages} pages", end="")
    print()

    if not args.no_verify:
        for i in range(npages):
            addr = args.base + i * PAGE
            port.write(b"R" + addr.to_bytes(3, "big"))
            port.timeout = 3.0
            rd = port.read(PAGE)
            want = data[i * PAGE:(i + 1) * PAGE].ljust(PAGE, b"\xFF")
            if rd != want:
                sys.exit(f"\nverify FAIL @0x{addr:06X}")
            print(f"\rverify {i + 1}/{npages} pages", end="")
        print()

    print(f"done: {len(data)} bytes flashed"
          + ("" if args.no_verify else " and verified"))


if __name__ == "__main__":
    main()

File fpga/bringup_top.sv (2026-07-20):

// bringup_top.sv — ULX3S bring-up + flash-writer for the Cartridge Pmod v0.1.
//
// Plug the cartridge into the ULX3S J1 header END columns, pins 1-12:
// the Pmod's VCC column mates J1 pins 1/2 (3.3V), GND column pins 3/4,
// signal columns land on GP/GN 0-3. Which cartridge row lands on GP vs GN
// depends on mechanical orientation, so the FSM probes both mappings and
// locks the one whose flash JEDEC ID reads back correctly:
//   mapping A: SCK=GP0 MISO=GP1 MOSI=GP2 FCS=GP3 / AUD=GN0 RCS=GN1 SD3=GN2 SD2=GN3
//   mapping B: rows swapped (GP <-> GN)
//
// Power-up test sequence (report on FTDI UART, 115200 8N1, and LEDs):
//   1. flash release-from-power-down (ABh), JEDEC ID (9Fh) == EF 40 18
//   2. PSRAM reset (66h/99h), read ID (9Fh) == 0D 5D
//   3. PSRAM memory test: two 4-byte write/read patterns at distinct
//      addresses + re-read of the first (aliasing check); CS-low bursts
//      kept ~5 us < the APS6404's 8 us tCEM limit
//   4. flash first 4 bytes read (03h) — reported, not judged (blank = FF)
//   5. 440 Hz sigma-delta test tone on the cartridge AUDIO pin
//
// After DONE the UART becomes a binary flash-writer console (driven by
// fpga/flash_cartridge.py; all multi-byte fields MSB first):
//   'I'                  -> 3 reply bytes: flash JEDEC ID
//   'E' a2 a1 a0         -> 4 KB sector erase @addr, replies 'K' when done
//   'P' a2 a1 a0 + 256B  -> page program @addr (page-aligned), replies 'K'
//   'R' a2 a1 a0         -> replies 256 bytes read from @addr
// WREN and SR1 busy-polling are handled internally.
//
// LEDs: 0 heartbeat / 1 flash OK / 2 PSRAM OK / 3 mem OK / 4 mapping B
//       5 done / 6 any-fail / 7 audio enabled.  BTN1 (fire1) re-runs.
`default_nettype none

module bringup_top #(
    parameter int BOOT_CYCLES = 500000,   // 20 ms rail settle
    parameter int UART_DIV    = 217       // 25 MHz / 115200
) (
    input  logic       clk_25mhz,
    input  logic [6:0] btn,        // btn[0] = PWR, pulled up, press = 0
    output logic [7:0] led,
    output logic       ftdi_rxd,   // FPGA -> FTDI -> PC
    input  logic       ftdi_txd,   // PC -> FTDI -> FPGA (flash-writer cmds)
    inout  wire  [3:0] pmod_gp,    // J1 header GP0-3
    inout  wire  [3:0] pmod_gn,    // J1 header GN0-3
    output logic       wifi_gpio0
);
    assign wifi_gpio0 = 1'b1;      // keep the ESP32 from powering the board off

    // ------------------------------------------------------------- reset ---
    logic [15:0] por = '0;
    wire rst = !btn[0] || !(&por);
    always_ff @(posedge clk_25mhz) if (!(&por)) por <= por + 16'd1;

    // ------------------------------------------------- pin mapping A / B ---
    logic map_b;                   // 0 = mapping A, 1 = mapping B
    logic sck, mosi, fcs_n, rcs_n, audio;
    logic miso;

    // outputs (SD2/SD3 = flash /WP //HOLD: hold high for plain SPI)
    assign pmod_gp[0] = map_b ? audio : sck;
    assign pmod_gp[1] = map_b ? rcs_n : 1'bz;      // A: MISO input
    assign pmod_gp[2] = map_b ? 1'b1  : mosi;      // B: SD3
    assign pmod_gp[3] = map_b ? 1'b1  : fcs_n;     // B: SD2
    assign pmod_gn[0] = map_b ? sck   : audio;
    assign pmod_gn[1] = map_b ? 1'bz  : rcs_n;     // B: MISO input
    assign pmod_gn[2] = map_b ? mosi  : 1'b1;
    assign pmod_gn[3] = map_b ? fcs_n : 1'b1;
    assign miso = map_b ? pmod_gn[1] : pmod_gp[1];

    // --------------------------------------------------------- SPI engine ---
    logic       sp_start, sp_busy, sp_done;
    logic [7:0] sp_tx, sp_rx;
    spi_byte u_spi (
        .clk(clk_25mhz), .rst(rst),
        .start(sp_start), .tx_byte(sp_tx), .rx_byte(sp_rx),
        .busy(sp_busy), .done(sp_done),
        .sck(sck), .mosi(mosi), .miso(miso)
    );

    // ------------------------------------------------- transaction table ---
    // ph 0-10: power-up tests; ph 16-21: flash-writer ops (dynamic fields)
    logic [4:0]  ph;
    logic [23:0] faddr;
    logic [7:0]  fcmd;             // 'E' / 'P' / 'R'
    logic        t_flash;
    logic [3:0]  t_ncmd, t_nrd;
    logic [63:0] t_cmd;
    always_comb begin
        t_flash = 1'b0; t_ncmd = 4'd1; t_nrd = 4'd0; t_cmd = 64'h0;
        case (ph)
            5'd0:  begin t_flash = 1'b1; t_ncmd = 4'd1; t_cmd = {8'hAB, 56'h0}; end
            5'd1:  begin t_flash = 1'b1; t_ncmd = 4'd1; t_nrd = 4'd3; t_cmd = {8'h9F, 56'h0}; end
            5'd2:  begin t_ncmd = 4'd1; t_cmd = {8'h66, 56'h0}; end
            5'd3:  begin t_ncmd = 4'd1; t_cmd = {8'h99, 56'h0}; end
            5'd4:  begin t_ncmd = 4'd4; t_nrd = 4'd2; t_cmd = {32'h9F000000, 32'h0}; end
            5'd5:  begin t_ncmd = 4'd8; t_cmd = {32'h02000000, 32'hAA55C33C}; end
            5'd6:  begin t_ncmd = 4'd4; t_nrd = 4'd4; t_cmd = {32'h03000000, 32'h0}; end
            5'd7:  begin t_ncmd = 4'd8; t_cmd = {32'h02012344, 32'h5AA50FF0}; end
            5'd8:  begin t_ncmd = 4'd4; t_nrd = 4'd4; t_cmd = {32'h03012344, 32'h0}; end
            5'd9:  begin t_ncmd = 4'd4; t_nrd = 4'd4; t_cmd = {32'h03000000, 32'h0}; end
            5'd10: begin t_flash = 1'b1; t_ncmd = 4'd4; t_nrd = 4'd4; t_cmd = {32'h03000000, 32'h0}; end
            // flash-writer ops (always flash CS)
            5'd16: begin t_flash = 1'b1; t_ncmd = 4'd1; t_cmd = {8'h06, 56'h0}; end
            5'd17: begin t_flash = 1'b1; t_ncmd = 4'd4; t_cmd = {8'h20, faddr, 32'h0}; end
            5'd18: begin t_flash = 1'b1; t_ncmd = 4'd4; t_cmd = {8'h02, faddr, 32'h0}; end // + 256B bulk
            5'd19: begin t_flash = 1'b1; t_ncmd = 4'd1; t_nrd = 4'd1; t_cmd = {8'h05, 56'h0}; end
            5'd20: begin t_flash = 1'b1; t_ncmd = 4'd4; t_cmd = {8'h03, faddr, 32'h0}; end // + 256B stream
            5'd21: begin t_flash = 1'b1; t_ncmd = 4'd1; t_nrd = 4'd3; t_cmd = {8'h9F, 56'h0}; end
            default: ;
        endcase
    end

    // -------------------------------------------------------- results ---
    logic [23:0] fid;
    logic [15:0] pid;
    logic [31:0] fdata, rxbuf;
    logic pass_f, pass_p, m1, m2, m3, tried_b, done_all;
    wire  pass_m = m1 && m2 && m3;

    // ------------------------------------------------------ UART rx/tx ---
    logic [7:0] rx_data;
    logic       rx_valid;
    uart_rx #(.DIV(UART_DIV)) u_urx (
        .clk(clk_25mhz), .rst(rst),
        .rx(ftdi_txd), .data(rx_data), .valid(rx_valid)
    );

    logic       u_busy;
    logic       f_wr;                    // flasher TX path
    logic [7:0] f_data;

    // ------------------------------------------------------- main FSM ---
    typedef enum logic [3:0] {
        S_BOOT, S_TSTART, S_TCMD, S_TREAD, S_TEND, S_DECIDE, S_REPORT, S_DONE,
        S_FRX, S_TBULK, S_TRDS, S_FREPLY
    } state_t;
    state_t st;
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

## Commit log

2026-07-19 Cartridge Pmod v0.1: schematic from qspi-pmod + tt-audio-pmod remix
    Stock QSPI Pmod pinout with PMOD8/uio[7] repurposed from CS2/PSRAM-B to
    sigma-delta audio (buffer + RC LPF + AC-coupled PJ-320B jack). PSRAM B
    deleted; CONFIG jumper block retained for memory isolation. Netlist
    machine-verified (tools/netlist_check.py). PCB layout pending KiCad.
    Claude-Session: https://claude.ai/code/session_01Xe5NzHvb72amxJFhr7WjZC
    [cartridge-pmod.kicad_pcb, cartridge-pmod.kicad_sch]
2026-07-19 ERC clean: add PWR_FLAG on filtered VCCA rail; export schematic PDF
    KiCad 10.0.4 ERC now passes with 0 errors (the 71 remaining warnings are
    missing-global-library noise from a CLI-only install, all symbols embedded).
    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
    [cartridge-pmod.kicad_sch]
2026-07-19 PCB layout complete: audio extension placed and routed, DRC at baseline
    Board extended 30.8->56.3mm for the audio section; jack at new right edge.
    PSRAM B removed (its dangling copper pruned), audio chain placed in three
    rows and fully routed on F.Cu; PMOD8 reuses the original CS2 B.Cu corridor
    and ducks under the +3.3V column; SCK rerouted after the PSRAM-B stub
    pruning cut it (taps PMOD4 B.Cu, via, F.Cu snake past U1.5). GND pours
    cover the extension on both layers with stitch vias; +3.3V zone restored
    to its original comb shape with a widened top column. DRC: 0 unconnected,
    errors identical to upstream qspi-pmod baseline (CONFIG jumper cut-traces
    + one pre-existing starved thermal).
    Co-A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
    [cartridge-pmod.kicad_pcb]
2026-07-19 Vendor reference designs and TT pmod lib as plain files; ignore .history
    The footprint library must travel with the repo (fp-lib-table points at it);
    refs/ upstream designs are Apache-2.0, vendored read-only.
    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
    [qspi-pmod.kicad_pcb, qspi-pmod.kicad_sch, tt-audio-pmod.kicad_pcb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]
2026-07-19 Silk cleanup: audio ref labels into row gaps, hide C13/R6, small text
    Silk warnings now identical to upstream baseline (J1 plug drawing only).
    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
    [cartridge-pmod.kicad_pcb]
2026-07-19 Pearto mascot on back silkscreen; fix stale PSRAM B CS jumper label
    Logo traced from pearto.jpeg (white background flood-removed, pear/hood
    outlines Moore-traced + RDP-simplified, eyes/mouth as parametric circles),
    8.6mm tall on B.Silkscreen above the jack anchors, X-mirrored for correct
    back-side viewing. Jumper legend for uio7 now reads AUDIO. DRC unchanged.
    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
    [cartridge-pmod.kicad_pcb]
2026-07-19 Pearto v2: round belly, smile, caption; add FABRICATION.md guide
    Pear/hood bottoms replaced with smooth half-ellipse belly, mouth is now a
    smile arc, caption Cartridge Pmod by JA on back silk. Step-by-step JLCPCB
    export+ordering guide in FABRICATION.md (Fabrication Toolkit or kicad-cli).
    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
    [cartridge-pmod.kicad_pcb]
2026-07-19 Fix 3D models: legacy path vars, renamed lib files, attach+align J3/RV1
    Legacy KICAD6/KICAD8 model vars and .wrl refs updated to KiCad 10 .step
    files (U1 wide-body SOIC-8 mapped to SOIC-8_5.3x5.3, U2 SOP-8 to
    SOIC-8_3.9x4.9 - same bodies). Vendored STEP models attached to J3 jack
    (rotZ 180, offY 2.6) and RV1 trim pot (rotX -90). Cosmetic only; no
    copper/fab change. Note: SWIG in-place edits of FP_3DMODEL members do not
    persist - rebuild the model list with clear+push_back (tools/model_rebuild.py).
    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
    [cartridge-pmod.kicad_pcb]
2026-07-19 J3 jack model Z-offset: body was sunk through the board
    Raised 2.5mm to sit on its mounting face; RV1 settled 0.3mm to flush.
    Final calibrated transforms are now the defaults in tools/model_rebuild.py
    (a single-part CLI override had silently reset J3 to stale defaults).
    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
    [cartridge-pmod.kicad_pcb]
2026-07-19 J3 model: anchor by mounting posts into NPTH holes (drop 2.6mm Y offset)
    The vendored STEP is a slightly different jack variant: its solder tabs sit
    2.6mm from the footprint pads, so posts-in-holes and tabs-on-pads cannot
    both hold. Posts are the physical anchor on the real part - align those.
    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
    [cartridge-pmod.kicad_pcb]
2026-07-19 Fix board-embedded TITLE/REVISION text variables (were stale QSPI-Pmod v2.2)
    The pcb file carries its own copy of the project text variables, used when
    the board is opened standalone; they still held the donor project values.
    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
    [cartridge-pmod.kicad_pcb]
2026-07-19 Strip UTF-8 BOM from board file (PS5.1 Set-Content artifact)
    The TITLE/REVISION fix was written with Set-Content -Encoding utf8, which
    in PowerShell 5.1 prepends a BOM; KiCad GUI refuses the file (kicad-cli
    tolerated it). Board content unchanged.
    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
    [cartridge-pmod.kicad_pcb]
2026-07-19 J3: exact C2884998 3D model via easyeda2kicad, calibrated seat
    Replaces the mismatched BOOMELE STEP (its pegs/tabs were for a different
    variant). Exact model: rot Z 270, offset (-0.6, 0, 3.3). Pegs enter the
    NPTH holes and, like the real part, do not protrude past the 1.6mm board.
    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
    [bom.csv, cartridge-pmod.kicad_pcb]
2026-07-20 Push LCSC supplier fields to board; first Fabrication Toolkit export
    F8 field sync so the toolkit reads LCSC Part from footprints (audio-section
    numbers exported blank before). production/ holds the JLC BOM/CPL/gerber zip.
    Claude-Session: https://claude.ai/code/session_01KoqFR2y5XeXxq4PQckdZZA
    [bom.csv, cartridge-pmod.kicad_pcb, cartridge-pmod.kicad_sch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]
2026-07-20 Silk cleanup + J1 promoted to JLC-assembled
    - Delete J1's 24 off-board silk pin drawings (18 silk_edge_clearance
    warnings -> 0; fab would clip them, connector body covers the area)
    - Nudge C11/C12/R5 label row off C13's pads; un-hide C13 and R6 labels
    - Clear DNP on J1 (board + schematic): C60565 header now in JLC BOM/CPL
    for economic THT assembly; J2 stays DNP (solder-jumper pattern)
    - Regenerate production/ via headless Fabrication Toolkit (-t -f -e -nI)
    - FABRICATION.md: document new J1 status + headless export recipe
    DRC after: 0 unconnected, 0 silk, only the 23 known-ignorable baseline
    errors (22 CONFIG cut-trace + 1 upstream starved thermal). ERC 0.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
    [bom.csv, cartridge-pmod.kicad_pcb, cartridge-pmod.kicad_sch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]
2026-07-20 ULX3S bring-up harness for the cartridge Pmod
    fpga/: self-checking bitstream — flash JEDEC ID + PSRAM ID + memory test
    (tCEM-safe 4-byte bursts) + 440 Hz sigma-delta tone on the audio chain,
    report on FTDI UART 115200. Plug-row orientation (GP vs GN) autodetected
    by retrying the flash ID with rows swapped; J1 header pins 1-12, sites
    from the official ulx3s_v20 constraints + v3.1.7 schematic.
    test/: cocotb + icarus, behavioral W25Q128/APS6404 models (PSRAM model
    enforces the 8us tCEM limit), both plug orientations simulated PASS.
    Bitstream: 898 LUTs, Fmax 113 MHz @ 25 MHz target, tristate MISO verified
    as $_TBUF_ in the netlist.
    Claud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
    [bringup_top.sv]
2026-07-20 README: fab status, bring-up harness, board/schematic images
    img/: fresh 3D top/iso/back renders (J1 now populated), 2D layout and
    schematic exports; root schematic PDF regenerated to match.
    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
2026-07-20 UART flash-writer: program the cartridge W25Q128 over the bring-up UART
    Same bitstream as the bring-up: after DONE the UART accepts a binary
    protocol ('I' ID / 'E' sector erase / 'P' page program / 'R' 256B read,
    WREN + SR1 busy-poll handled in-FSM), reusing the transaction engine as
    dynamic phases 16-21. fpga/flash_cartridge.py is the pyserial host side:
    drain report -> ID handshake -> erase covered sectors -> program pages ->
    verify. This closes the last gap for cartridge-boot: bring-up PASS ->
    flash image -> swap to tt-riscv rv32_cartridge.bit -> TinyRV32 XIP-boots.
    test/: flash model grew WEL/erase/program/SR1-busy semantics (busy as a
    one-shot timer — $realtime in a wire expr never r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
    [bringup_top.sv, flash_cartridge.py]
